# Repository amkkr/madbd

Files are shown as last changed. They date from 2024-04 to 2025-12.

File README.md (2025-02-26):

# madbd

最下段のキー数が少ないおおむね格子状のキーボード

## Images

### 0.0.1

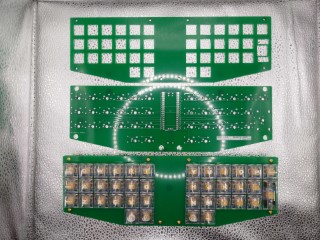
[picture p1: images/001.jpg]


### 0.0.2

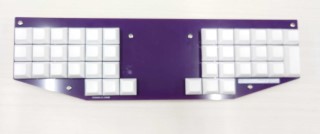
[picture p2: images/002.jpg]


### 0.0.3

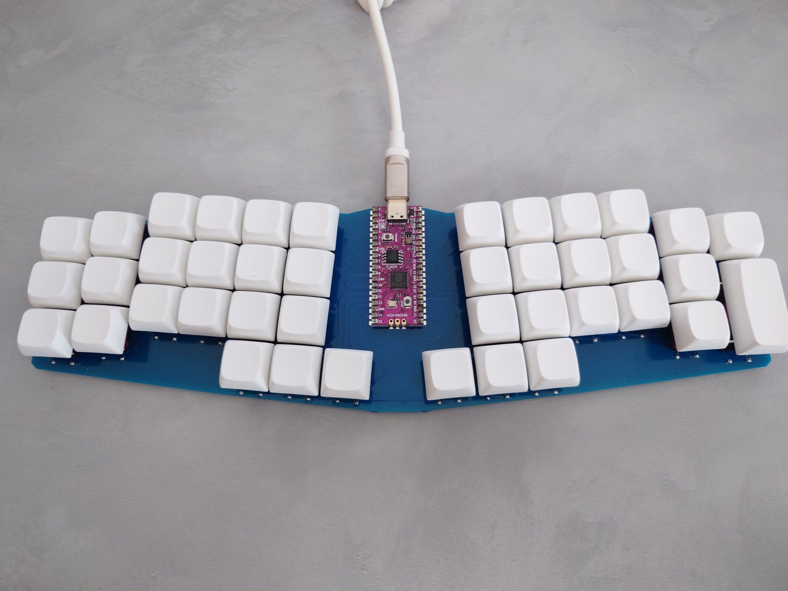
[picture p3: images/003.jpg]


### 1.0.0

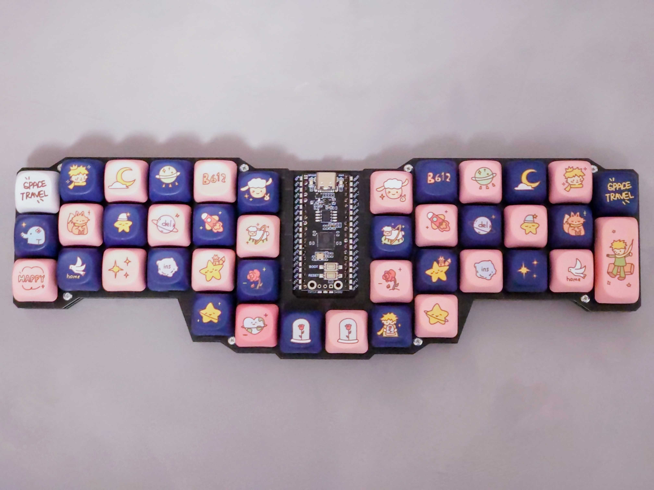
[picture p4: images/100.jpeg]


## Show Links

- raspberry pi pico datasheet
  - <https://datasheets.raspberrypi.com/pico/pico-datasheet.pdf>
- raspberry pi pico KiCad files
  - <https://datasheets.raspberrypi.com/rp2040/VGA-KiCAD.zip>
- Automated wiring tool
  - <https://github.com/freerouting/freerouting>

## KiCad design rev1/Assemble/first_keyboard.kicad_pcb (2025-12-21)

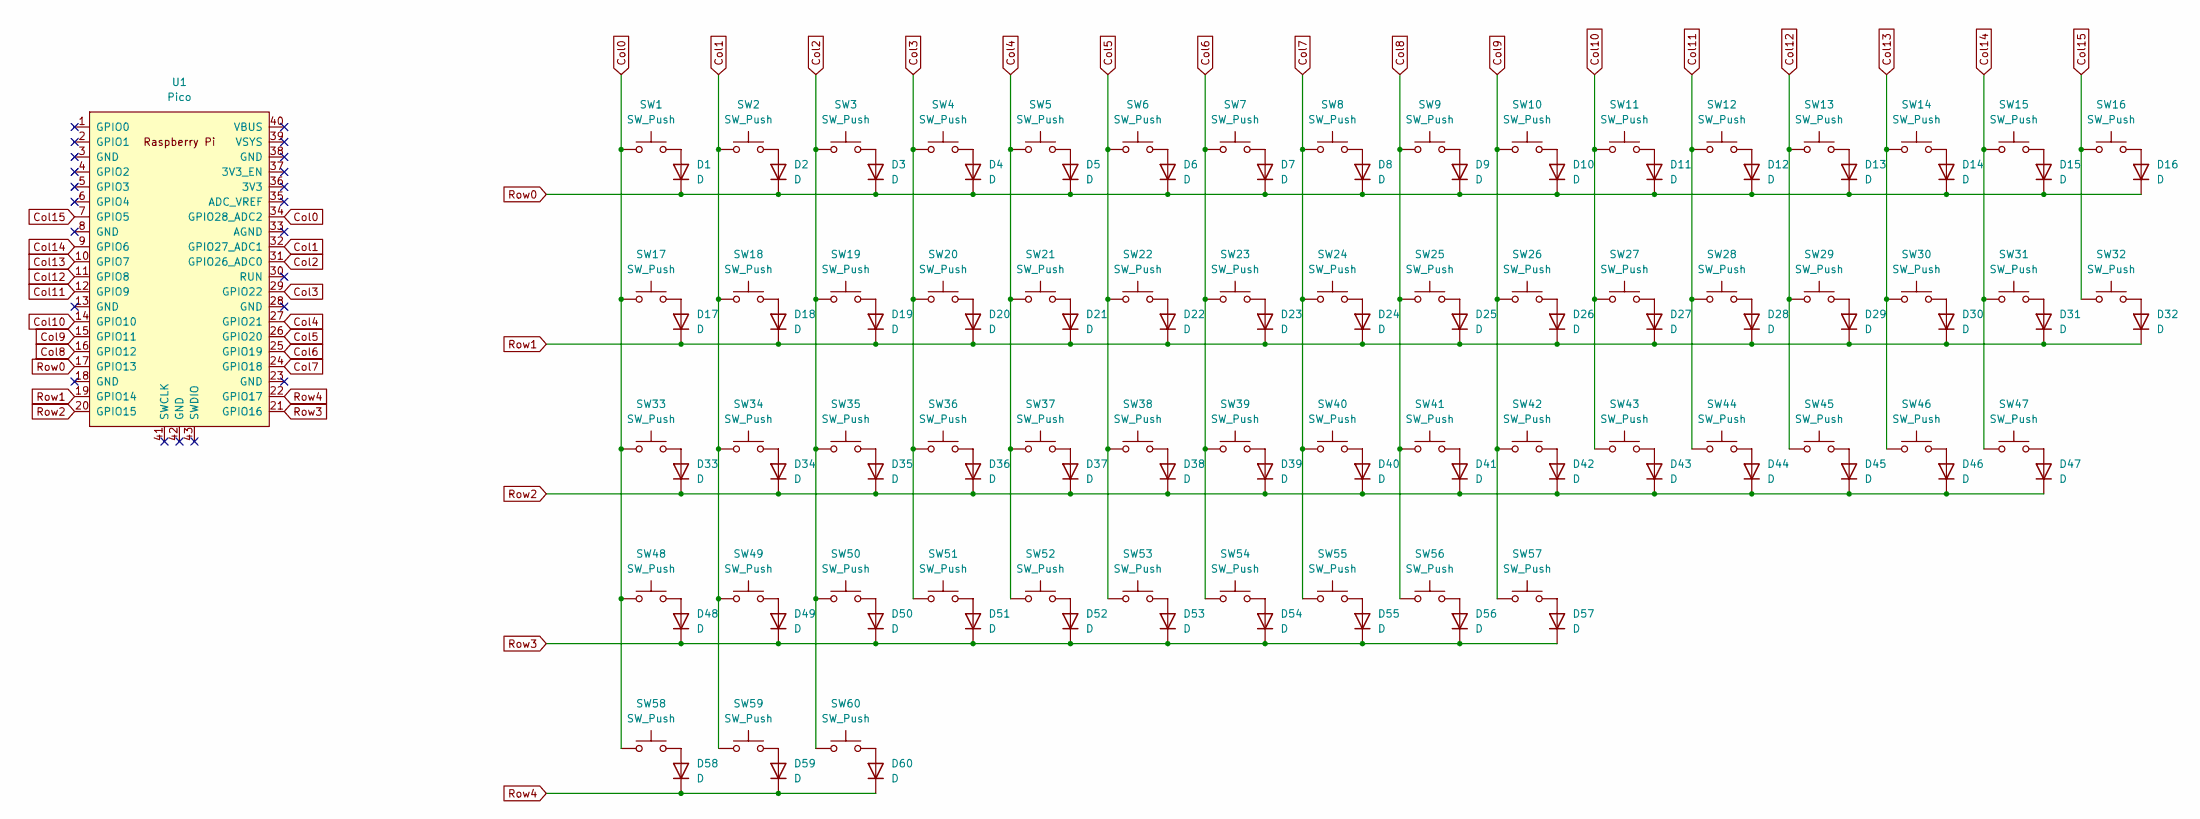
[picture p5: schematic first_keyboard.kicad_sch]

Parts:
D1, D2, D3, D4, D5, D6, D7, D8, D9, D10, D11, D12, D13, D14, D15, D16, D17, D18, D19, D20, D21, D22, D23, D24, D25, D26, D27, D28, D29, D30, D31, D32, D33, D34, D35, D36, D37, D38, D39, D40, D41, D42, D43, D44, D45, D46, D47, D48, D49, D50, D51, D52, D53, D54, D55, D56, D57, D58, D59, D60: D; Diode_TH_SMD
SW1, SW2, SW3, SW4, SW5, SW6, SW7, SW8, SW9, SW10, SW11, SW12, SW13, SW14, SW15, SW16, SW17, SW18, SW19, SW20, SW21, SW22, SW23, SW24, SW25, SW26, SW27, SW28, SW29, SW30, SW31, SW33, SW34, SW35, SW36, SW37, SW38, SW39, SW40, SW41, SW42, SW43, SW44, SW45, SW46, SW47, SW48, SW49, SW50, SW51, SW52, SW53, SW54, SW55, SW56, SW57, SW59, SW60: SW_Push; CherryMX_Hotswap_1u
SW32, SW58: SW_Push; CherryMX_Hotswap_2u
U1: Pico; RPi_Pico_SMD_TH

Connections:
Col0: SW1.1, SW17.1, SW33.1, SW48.1, SW58.1, U1.34 (GPIO28_ADC2)
Col1: SW2.1, SW18.1, SW34.1, SW49.1, SW59.1, U1.32 (GPIO27_ADC1)
Col2: SW3.1, SW19.1, SW35.1, SW50.1, SW60.1, U1.31 (GPIO26_ADC0)
Col3: SW4.1, SW20.1, SW36.1, SW51.1, U1.29 (GPIO22)
Col4: SW5.1, SW21.1, SW37.1, SW52.1, U1.27 (GPIO21)
Col5: SW6.1, SW22.1, SW38.1, SW53.1, U1.26 (GPIO20)
Col6: SW7.1, SW23.1, SW39.1, SW54.1, U1.25 (GPIO19)
Col7: SW8.1, SW24.1, SW40.1, SW55.1, U1.24 (GPIO18)
Col8: SW9.1, SW25.1, SW41.1, SW56.1, U1.16 (GPIO12)
Col9: SW10.1, SW26.1, SW42.1, SW57.1, U1.15 (GPIO11)
Col10: SW11.1, SW27.1, SW43.1, U1.14 (GPIO10)
Col11: SW12.1, SW28.1, SW44.1, U1.12 (GPIO9)
Col12: SW13.1, SW29.1, SW45.1, U1.11 (GPIO8)
Col13: SW14.1, SW30.1, SW46.1, U1.10 (GPIO7)
Col14: SW15.1, SW31.1, SW47.1, U1.9 (GPIO6)
Col15: SW16.1, SW32.1, U1.7 (GPIO5)
unnamed: D1.2 (A), SW1.2
unnamed: D2.2 (A), SW2.2
unnamed: D3.2 (A), SW3.2
unnamed: D4.2 (A), SW4.2
unnamed: D5.2 (A), SW5.2
unnamed: D6.2 (A), SW6.2
unnamed: D7.2 (A), SW7.2
unnamed: D8.2 (A), SW8.2
unnamed: D9.2 (A), SW9.2
unnamed: D10.2 (A), SW10.2
unnamed: D11.2 (A), SW11.2
unnamed: D12.2 (A), SW12.2
unnamed: D13.2 (A), SW13.2
unnamed: D14.2 (A), SW14.2
unnamed: D15.2 (A), SW15.2
unnamed: D16.2 (A), SW16.2
unnamed: D17.2 (A), SW17.2
unnamed: D18.2 (A), SW18.2
unnamed: D19.2 (A), SW19.2
unnamed: D20.2 (A), SW20.2
unnamed: D21.2 (A), SW21.2
unnamed: D22.2 (A), SW22.2
unnamed: D23.2 (A), SW23.2
unnamed: D24.2 (A), SW24.2
unnamed: D25.2 (A), SW25.2
unnamed: D26.2 (A), SW26.2
unnamed: D27.2 (A), SW27.2
unnamed: D28.2 (A), SW28.2
unnamed: D29.2 (A), SW29.2
unnamed: D30.2 (A), SW30.2
unnamed: D31.2 (A), SW31.2
unnamed: D32.2 (A), SW32.2
unnamed: D33.2 (A), SW33.2
unnamed: D34.2 (A), SW34.2
unnamed: D35.2 (A), SW35.2
unnamed: D36.2 (A), SW36.2
unnamed: D37.2 (A), SW37.2
unnamed: D38.2 (A), SW38.2
unnamed: D39.2 (A), SW39.2
unnamed: D40.2 (A), SW40.2
unnamed: D41.2 (A), SW41.2
unnamed: D42.2 (A), SW42.2
unnamed: D43.2 (A), SW43.2
unnamed: D44.2 (A), SW44.2
unnamed: D45.2 (A), SW45.2
unnamed: D46.2 (A), SW46.2
unnamed: D47.2 (A), SW47.2
unnamed: D48.2 (A), SW48.2
unnamed: D49.2 (A), SW49.2
unnamed: D50.2 (A), SW50.2
unnamed: D51.2 (A), SW51.2
unnamed: D52.2 (A), SW52.2
unnamed: D53.2 (A), SW53.2
unnamed: D54.2 (A), SW54.2
unnamed: D55.2 (A), SW55.2
unnamed: D56.2 (A), SW56.2
unnamed: D57.2 (A), SW57.2
unnamed: D58.2 (A), SW58.2
unnamed: D59.2 (A), SW59.2
unnamed: D60.2 (A), SW60.2
Row0: D1.1 (K), D2.1 (K), D3.1 (K), D4.1 (K), D5.1 (K), D6.1 (K), D7.1 (K), D8.1 (K), D9.1 (K), D10.1 (K), D11.1 (K), D12.1 (K), D13.1 (K), D14.1 (K), D15.1 (K), D16.1 (K), U1.17 (GPIO13)
Row1: D17.1 (K), D18.1 (K), D19.1 (K), D20.1 (K), D21.1 (K), D22.1 (K), D23.1 (K), D24.1 (K), D25.1 (K), D26.1 (K), D27.1 (K), D28.1 (K), D29.1 (K), D30.1 (K), D31.1 (K), D32.1 (K), U1.19 (GPIO14)
Row2: D33.1 (K), D34.1 (K), D35.1 (K), D36.1 (K), D37.1 (K), D38.1 (K), D39.1 (K), D40.1 (K), D41.1 (K), D42.1 (K), D43.1 (K), D44.1 (K), D45.1 (K), D46.1 (K), D47.1 (K), U1.20 (GPIO15)
Row3: D48.1 (K), D49.1 (K), D50.1 (K), D51.1 (K), D52.1 (K), D53.1 (K), D54.1 (K), D55.1 (K), D56.1 (K), D57.1 (K), U1.21 (GPIO16)
Row4: D58.1 (K), D59.1 (K), D60.1 (K), U1.22 (GPIO17)

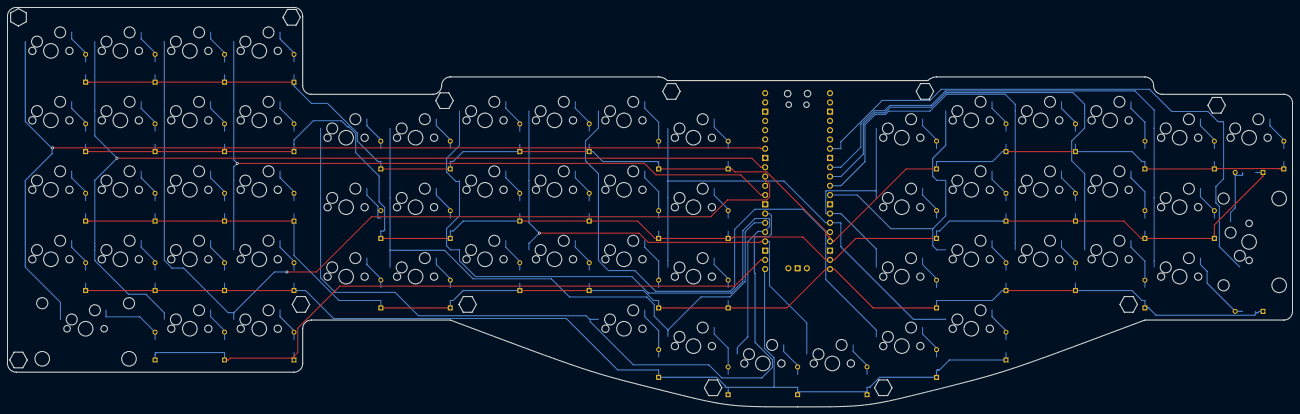
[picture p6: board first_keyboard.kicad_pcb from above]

Board: 2 copper layers, 352.4 x 109.5 mm, 133 parts (1 on the bottom side), 81 nets.

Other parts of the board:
ref1, ref2, ref3, ref4, ref5, ref6, ref7, ref8, ref9, ref11, ref12, ref13: val; m2_Spacer_Hole_hex

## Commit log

2024-03-01 feat: key switches wiring
    [first_keyboard.kicad_pcb, first_keyboard.kicad_sch]
2024-03-03 feat: change rasp pico
    [first_keyboard.kicad_sch]
2024-03-08 feat: picoに配線した
    [first_keyboard.kicad_sch]
2024-03-08 feat: PWR_FLAG違反修正
    [first_keyboard.kicad_sch]
2024-03-09 feat: ナンバリング修正
    [first_keyboard.kicad_sch]
2024-03-21 feat: pcbのスイッチ整列\
    [first_keyboard.kicad_pcb, first_keyboard.kicad_sch]
2024-03-21 feat:ダイオードの番号降り直しと整列\
    [first_keyboard.kicad_pcb, first_keyboard.kicad_sch]
2024-03-21 feat: すべて整列済み\
    [first_keyboard.kicad_pcb]
2024-03-21 feat: ダイオードそろえた
    [first_keyboard.kicad_pcb]
2024-03-21 add: Top plate
    [first_keyboard.kicad_pcb]
2024-03-21 feat: m3spacer
    [first_keyboard.kicad_pcb]
2024-03-21 feat: picoを裏面に
    [first_keyboard.kicad_pcb]
2024-03-21 add: Bottom
    [first_keyboard.kicad_pcb]
2024-03-21 feat: ダイオードをスイッチの近くに大移動
    [first_keyboard.kicad_pcb, first_keyboard.kicad_sch]
2024-03-21 feat: 配線
    [first_keyboard.dsn]
2024-03-23 add: PCB drill files
    [first_keyboard-B_Cu.gbr, first_keyboard-B_Mask.gbr, first_keyboard-B_Silkscreen.gbr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]
2024-03-23 add: Top-plate drill files
    [first_keyboard-B_Cu.gbr, first_keyboard-B_Mask.gbr, first_keyboard-B_Silkscreen.gbr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]
2024-03-23 add: Bottom-plate drill files
    [first_keyboard-B_Cu.gbr, first_keyboard-B_Mask.gbr, first_keyboard-B_Silkscreen.gbr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]
2024-04-06 fix: ボードの反転を意識してタグを振りなおした
    [first_keyboard.kicad_sch]
2024-04-06 fix: ねじ穴に変更
    [first_keyboard.kicad_pcb, first_keyboard.kicad_sch]
2024-04-06 feat: 回路図にスイッチを追加
    [first_keyboard.kicad_pcb, first_keyboard.kicad_sch]
2024-04-06 feat: 新デザインと配線
    [first_keyboard.dsn, first_keyboard.kicad_pcb]
2024-04-06 feat: 外形追加、pdf更新
    [first_keyboard.kicad_pcb]
2024-04-07 feat: 外形更新、スルーホール追加、配線追加
    [first_keyboard.dsn, first_keyboard.kicad_pcb]
2024-04-07 add: top_plate
    [first_keyboard.kicad_pcb]
2024-04-07 delete: Bottom
    [first_keyboard.kicad_pcb]
2024-04-07 feat: 刻印追加
    [first_keyboard.kicad_pcb]
2024-04-07 add: gerber出力
    [first_keyboard-B_Cu.gbr, first_keyboard-B_Mask.gbr, first_keyboard-B_Silkscreen.gbr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]
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2024-05-12 feat: 回路図をpicoがスイッチと同じ面に来る想定のものに変更
    [first_keyboard.kicad_sch]
2024-05-12 feat: PCBの配置を変更
    [first_keyboard.kicad_pcb]
2024-05-12 fix: 左右とpicoの整列
    [first_keyboard.kicad_pcb]
2024-05-12 feat: 角度8, 左右幅初期位置
    [first_keyboard.kicad_pcb]
2024-05-12 feat: lotate 12, width 4
    [first_keyboard.kicad_pcb]
2024-06-30 feat: lotate 10 両端のキーは無回転
    [first_keyboard.kicad_pcb]
2024-08-03 feat: 小指カラムをさげる part1
    [first_keyboard.kicad_pcb, first_keyboard.kicad_sch]
2024-08-03 feat: 小指カラムをさげる part2
    [first_keyboard.kicad_pcb]
2024-08-03 fix: 配線を修正
    [first_keyboard.kicad_pcb]
2024-08-03 feat: dsnファイルを最新に
    [first_keyboard.dsn]
2024-08-03 feat: 縦配線を追加
    [first_keyboard.kicad_pcb]
2024-08-03 feat: Col0の配線と左手カソードの配線
    [first_keyboard.kicad_pcb]
2024-08-03 feat: →手カソードの配線
    [first_keyboard.kicad_pcb]
2024-08-03 feat: col0の配線修正
    [first_keyboard.kicad_pcb]
2024-08-03 feat: 左側配線終了
    [first_keyboard.kicad_pcb]
2024-08-03 feat: 90度排除
    [first_keyboard.kicad_pcb]
2024-08-04 feat: ガーバーファイル出力
    [first_keyboard-B_Cu.gbr, first_keyboard-B_Mask.gbr, first_keyboard-B_Silkscreen.gbr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]
2024-08-04 fix: ファイル閉じた際の更新
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2024-09-07 fix: remove sch ERC error
    [first_keyboard.kicad_sch]
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2024-09-07 feat: 外形線修正
    [first_keyboard.kicad_pcb]
2024-09-07 feat: ダイオード位置変更
    [first_keyboard.kicad_pcb]
2024-09-08 feat: 輪郭線変更
    [first_keyboard.kicad_pcb]
2024-09-08 feat: スペース繋げて外形変更
    [first_keyboard.kicad_pcb]
2024-09-08 feat: Topからダイオード削除
    [first_keyboard.kicad_pcb]
2024-09-08 feat: Topネジ穴追加
    [first_keyboard.kicad_pcb]
2024-09-08 feat: ダイオード実装面変更
    [first_keyboard.kicad_pcb]
2024-09-08 feat: ６角スペーサー穴追加
    [first_keyboard.kicad_pcb]
2024-09-08 feat: pcbのネジ穴にRevを振る
    [first_keyboard.dsn, first_keyboard.kicad_pcb]
2024-09-08 feat: TOPに模様追加
    [first_keyboard.kicad_pcb]
2024-09-08 feat: ドリルファイル生成
    [first_keyboard-B_Cu.gbl, first_keyboard-B_Cu.gbr, first_keyboard-B_Mask.gbr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]
2024-09-22 fix: ダイオード位置を変更
    [first_keyboard.kicad_pcb]
2024-09-22 update: drill file
    [first_keyboard-B_Cu.gbl, first_keyboard-B_Mask.gbs, first_keyboard-B_Silkscreen.gbo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]
2024-09-22 update: plot-file
    [first_keyboard-B_Cu.gbl, first_keyboard-B_Cu.gbr, first_keyboard-B_Mask.gbr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]
2024-09-22 delete: PCB gerber
    [first_keyboard-B_Cu.gbl, first_keyboard-B_Mask.gbs, first_keyboard-B_Silkscreen.gbo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]
2024-09-22 update: 配線とドリルファイルの更新
    [first_keyboard-B_Cu.gbr, first_keyboard-B_Mask.gbr, first_keyboard-B_Silkscreen.gbr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]
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2025-11-20 update: kicadバージョン
    [first_keyboard-B_Cu.gbr, first_keyboard-B_Mask.gbr, first_keyboard-B_Silkscreen.gbr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]
2025-11-29 feat: スイッチとダイオードは置いた
    [first_keyboard.kicad_sch]
2025-11-30 feat: 回路図引いた
    [first_keyboard.kicad_sch]
2025-11-30 feat: ラベル付け直しとフットプリント指定
    [first_keyboard.kicad_pcb, first_keyboard.kicad_sch]
2025-11-30 feat: PCB部品配置
    [first_keyboard.kicad_pcb]
2025-11-30 feat: アウトライン作成
    [first_keyboard.kicad_pcb]
2025-12-01 feat: dir整理,
    [first_keyboard.dsn, first_keyboard.kicad_pcb, first_keyboard.kicad_sch]
2025-12-01 feat: スペーサー穴追加
    [first_keyboard.kicad_pcb]
2025-12-01 add: Topプレート追加
    [first_keyboard_top.kicad_pcb, first_keyboard_top.kicad_sch]
2025-12-01 feat: ネジ穴位置調整
    [first_keyboard.dsn, first_keyboard.kicad_pcb, first_keyboard_top.kicad_pcb]
2025-12-01 add: fox
    [first_keyboard_top.kicad_pcb]
2025-12-01 add: gerber
    [first_keyboard-B_Cu.gbr, first_keyboard-B_Mask.gbr, first_keyboard-B_Silkscreen.gbr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]
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
